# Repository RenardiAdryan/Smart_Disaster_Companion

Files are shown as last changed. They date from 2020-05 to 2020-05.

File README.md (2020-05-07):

# Smart_Disaster_Companion

This project is aimed to provide early warning system for fire.
it has IOT system that connect to the server, so users can know where the fire occured.
This thing will be connected with web application VIA firebase.com 

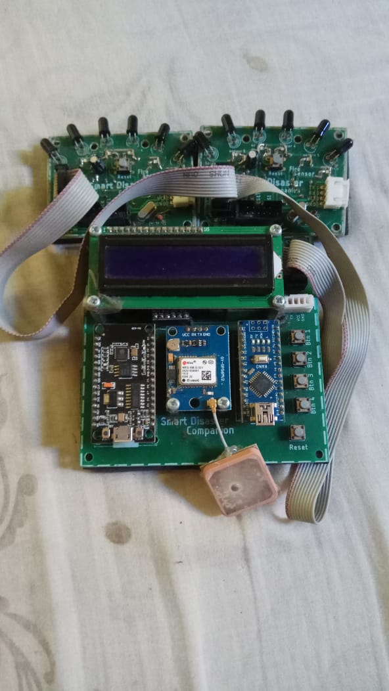
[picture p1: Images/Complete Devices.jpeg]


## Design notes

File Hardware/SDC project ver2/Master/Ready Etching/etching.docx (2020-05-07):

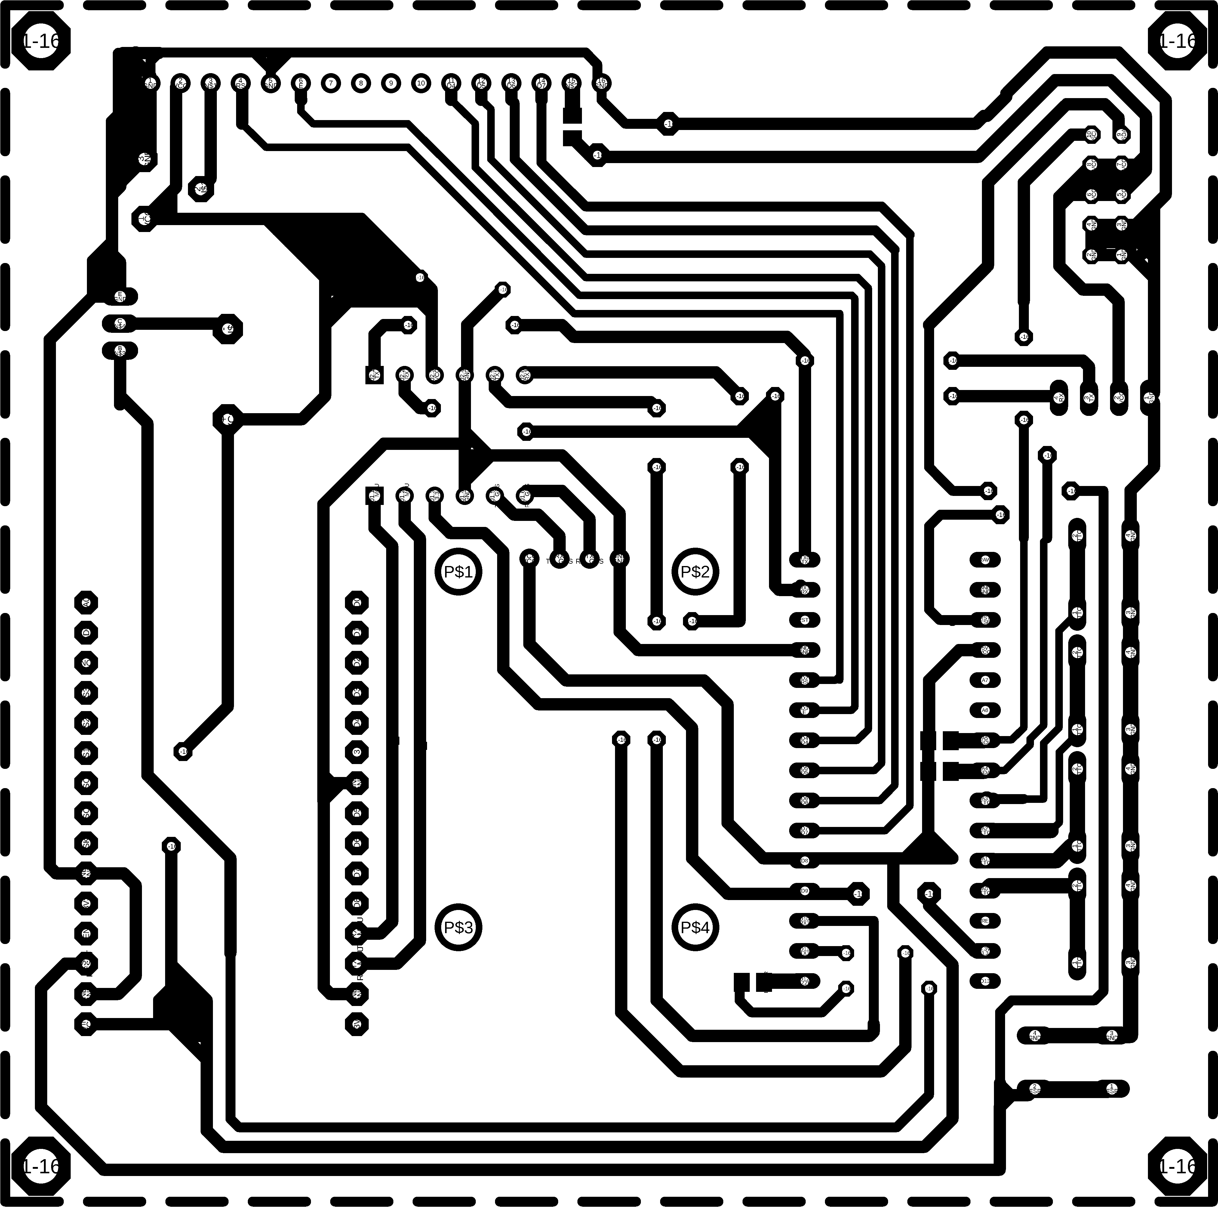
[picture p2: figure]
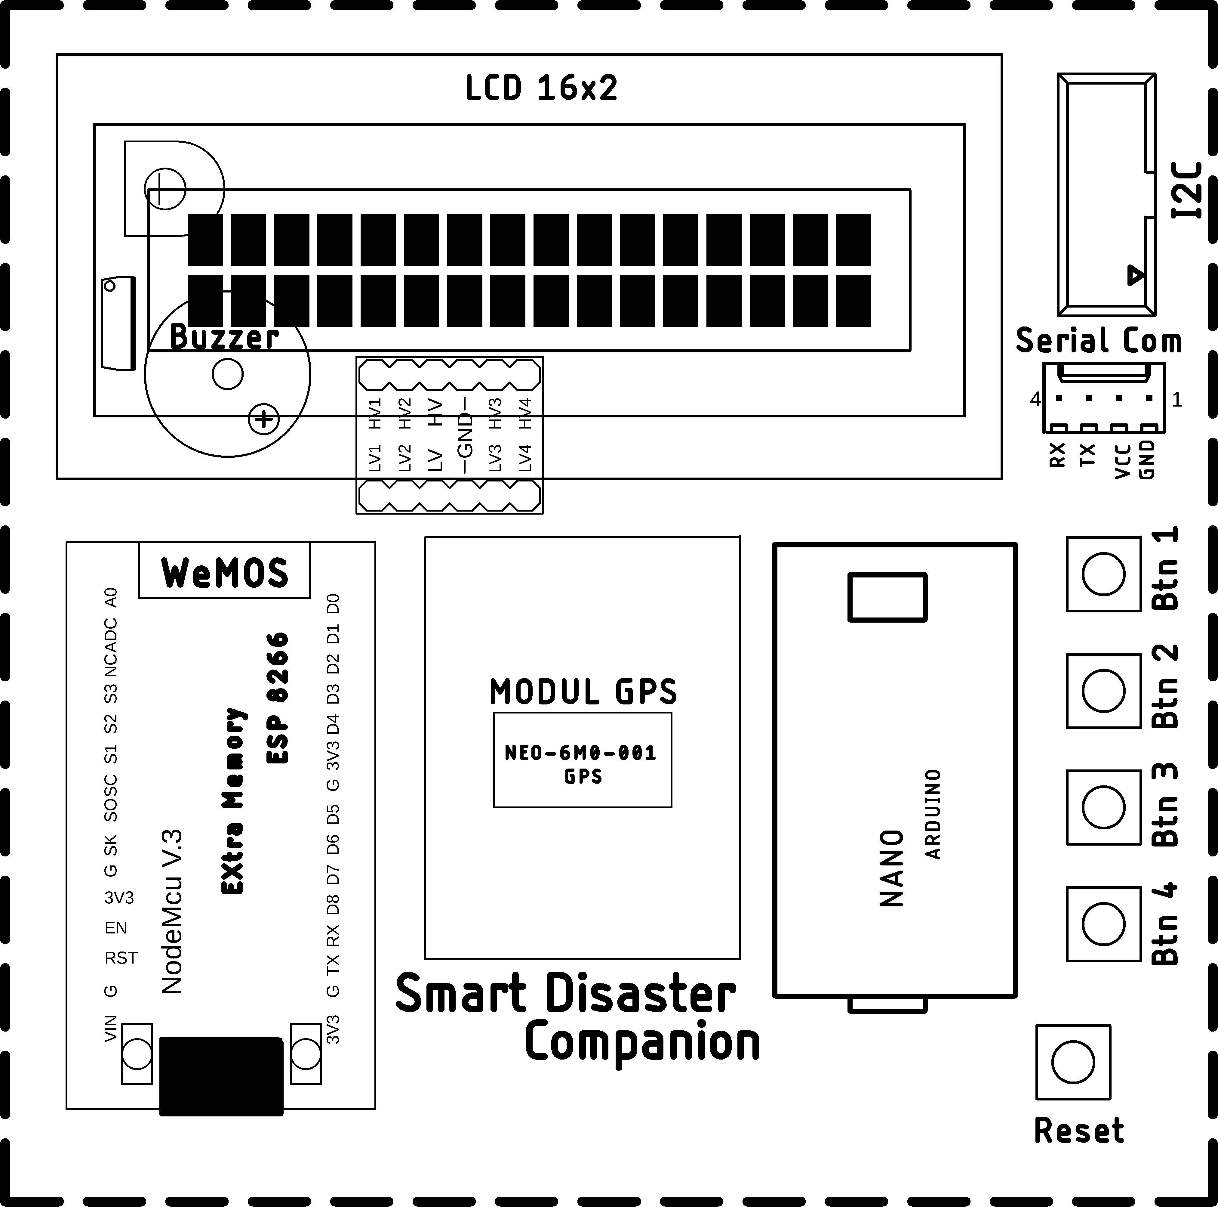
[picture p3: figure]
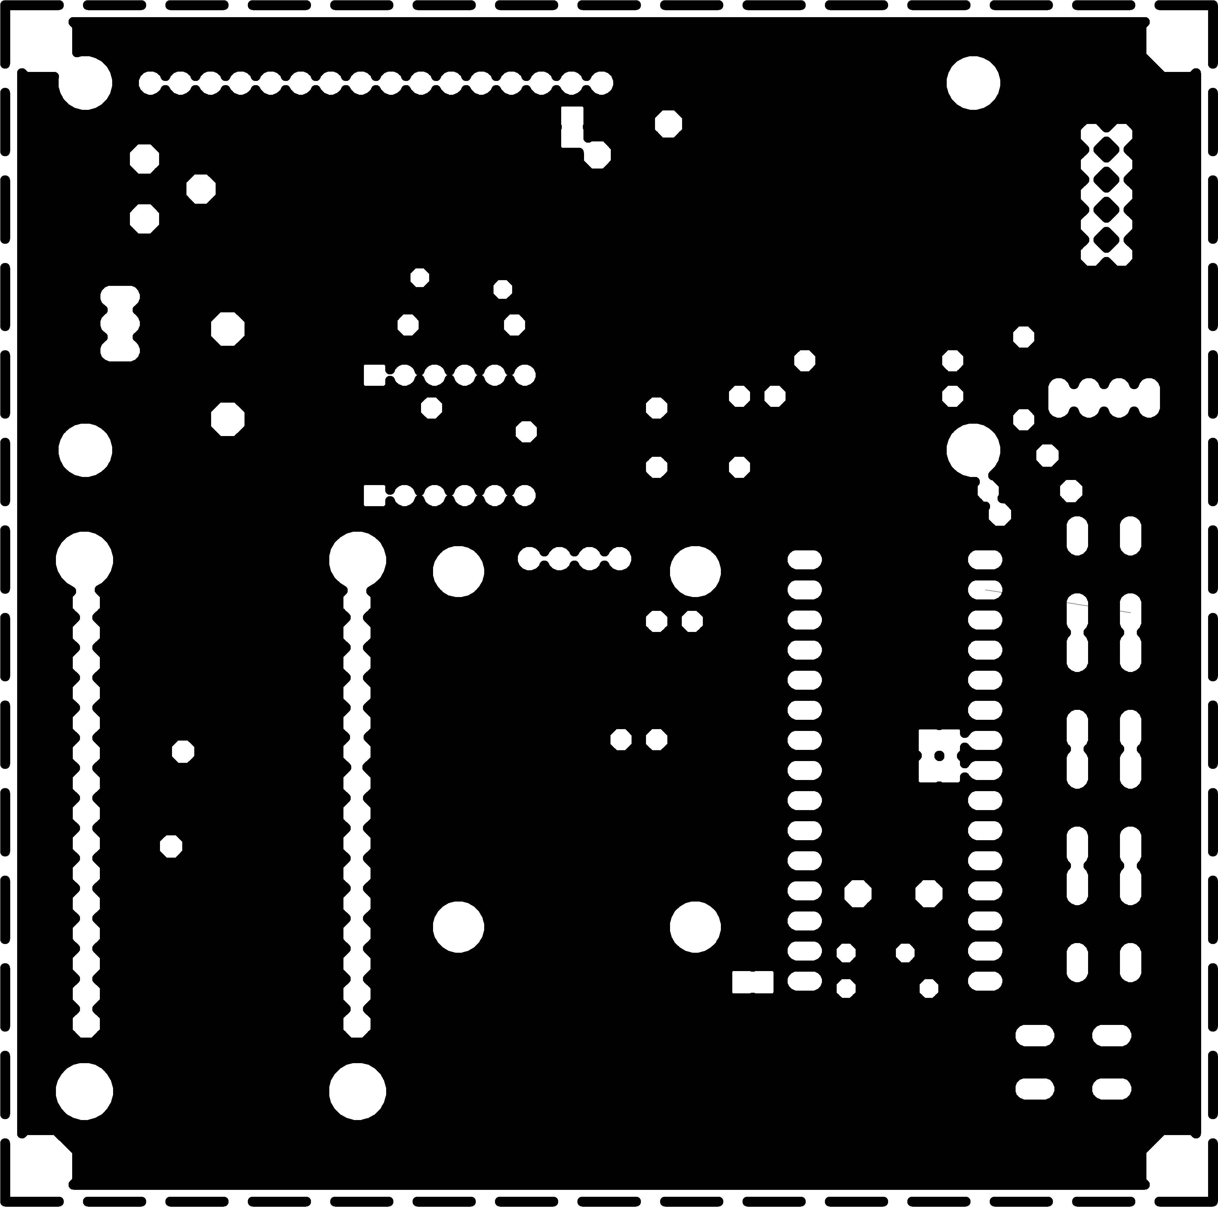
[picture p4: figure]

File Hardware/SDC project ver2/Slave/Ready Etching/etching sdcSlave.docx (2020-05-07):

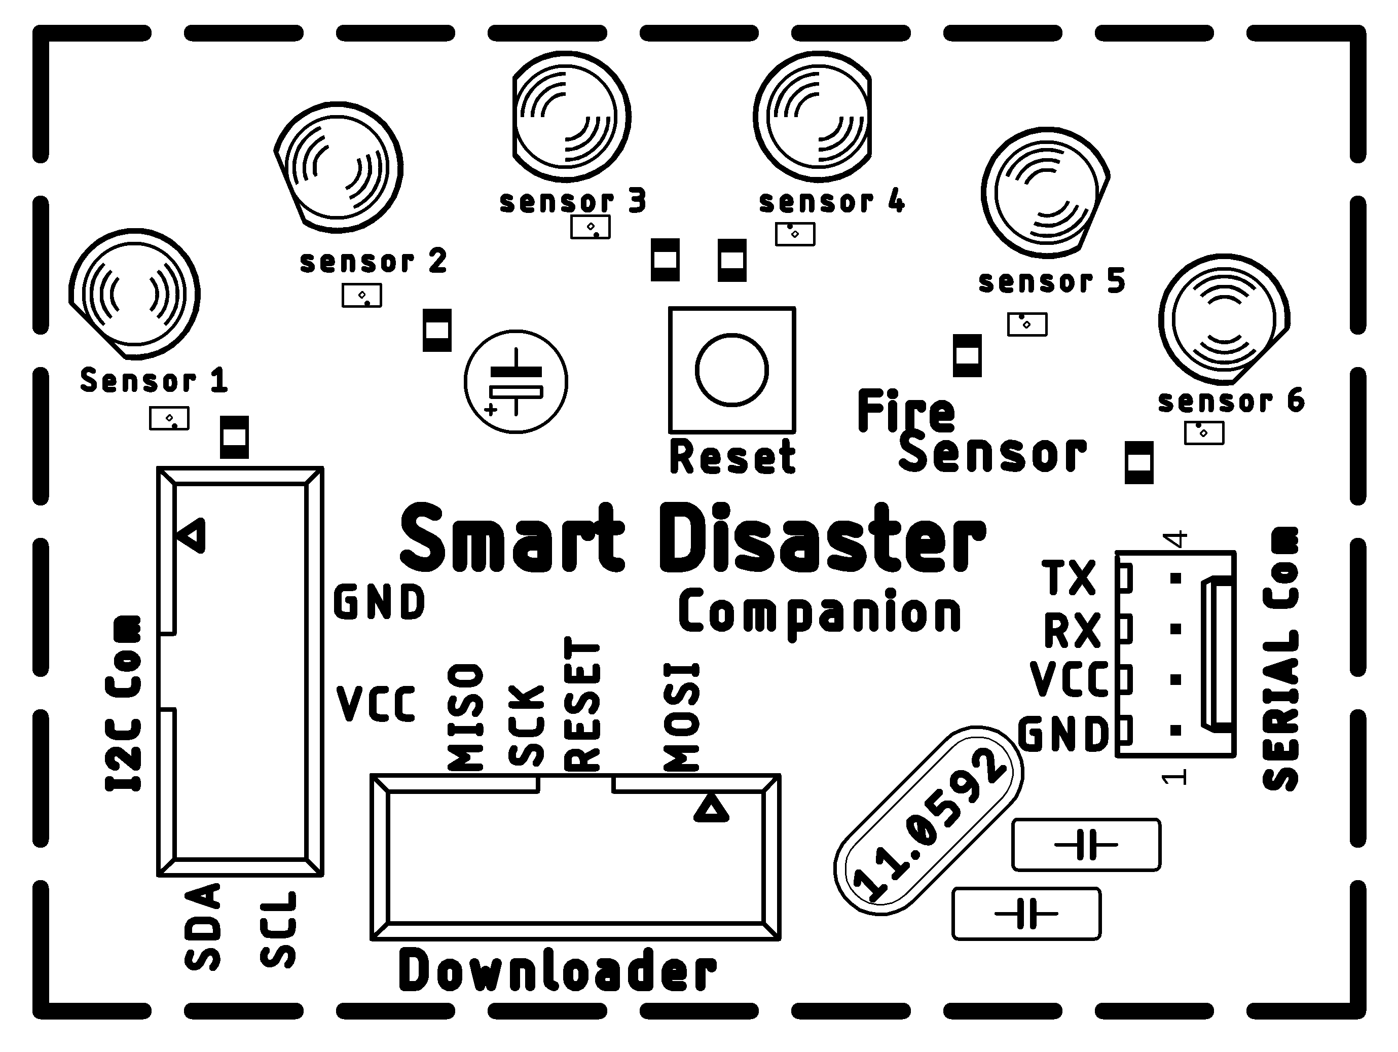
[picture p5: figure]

Silk Screen

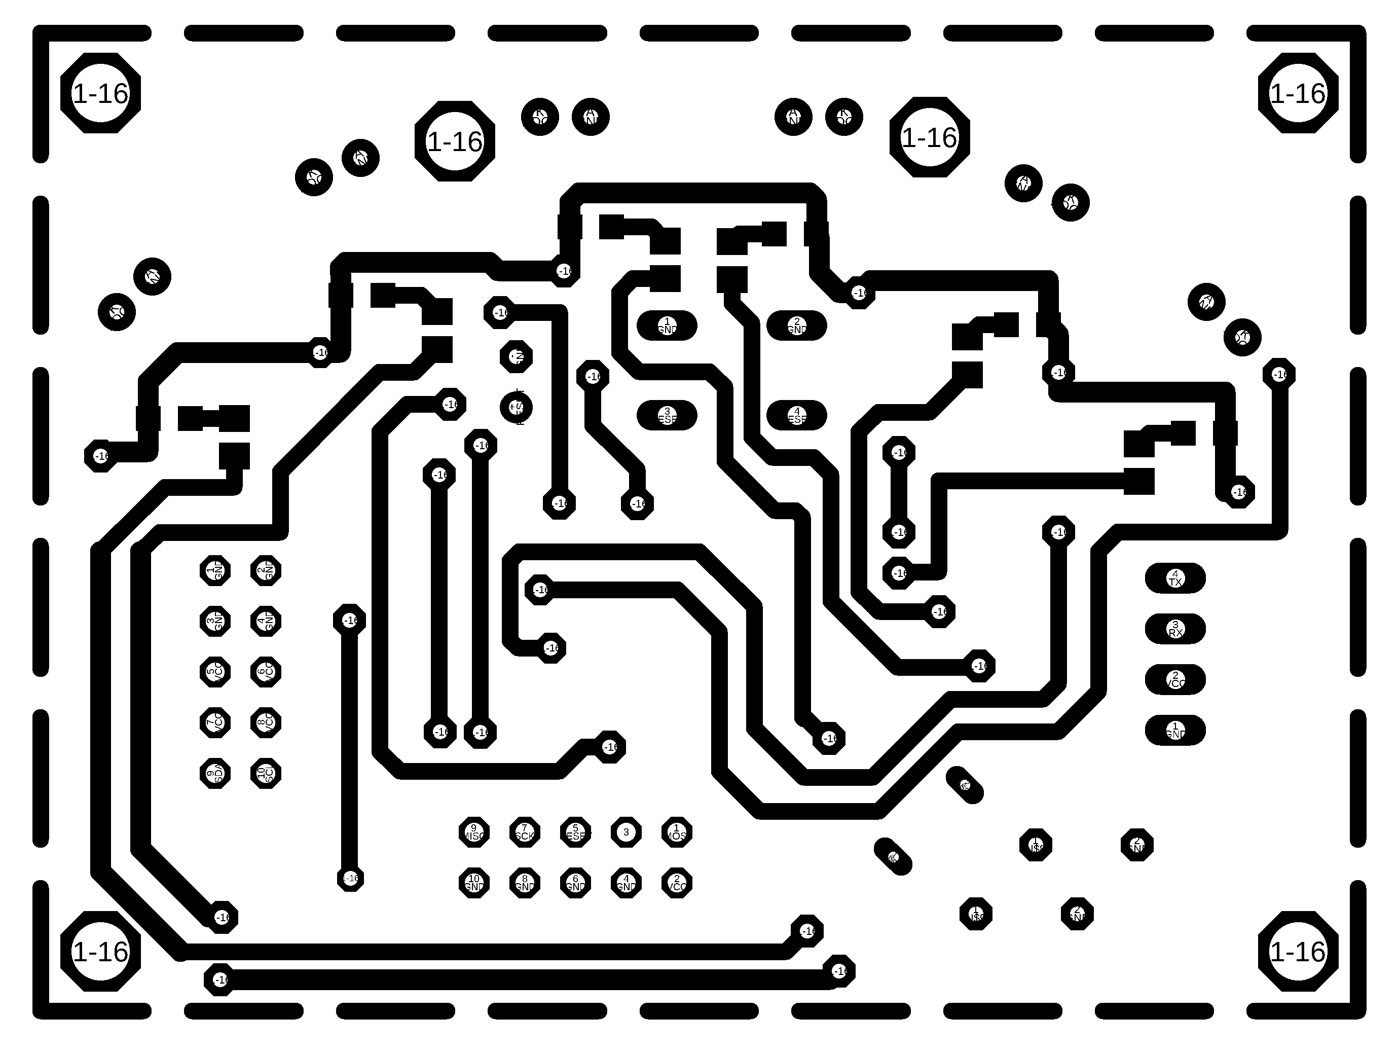
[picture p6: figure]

TOP

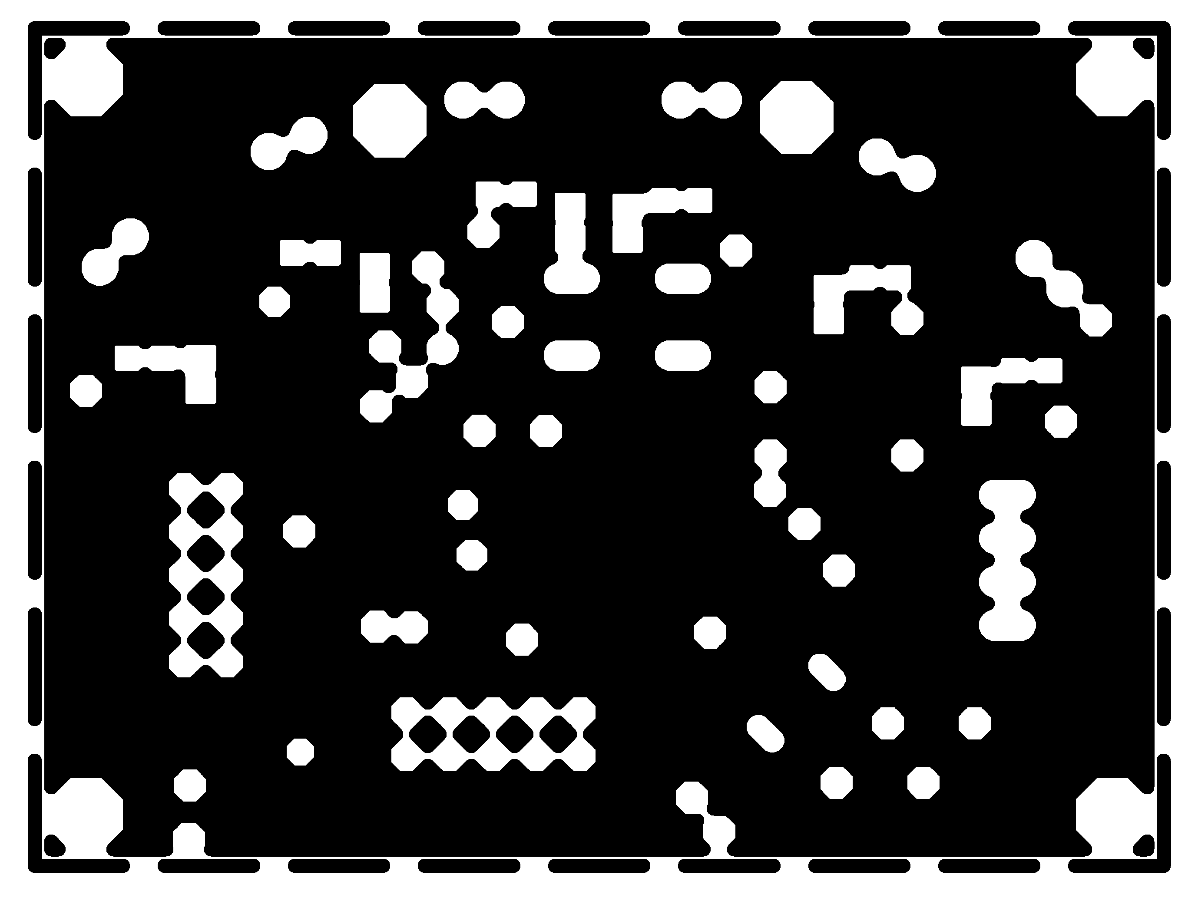
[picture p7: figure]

Masking TOP

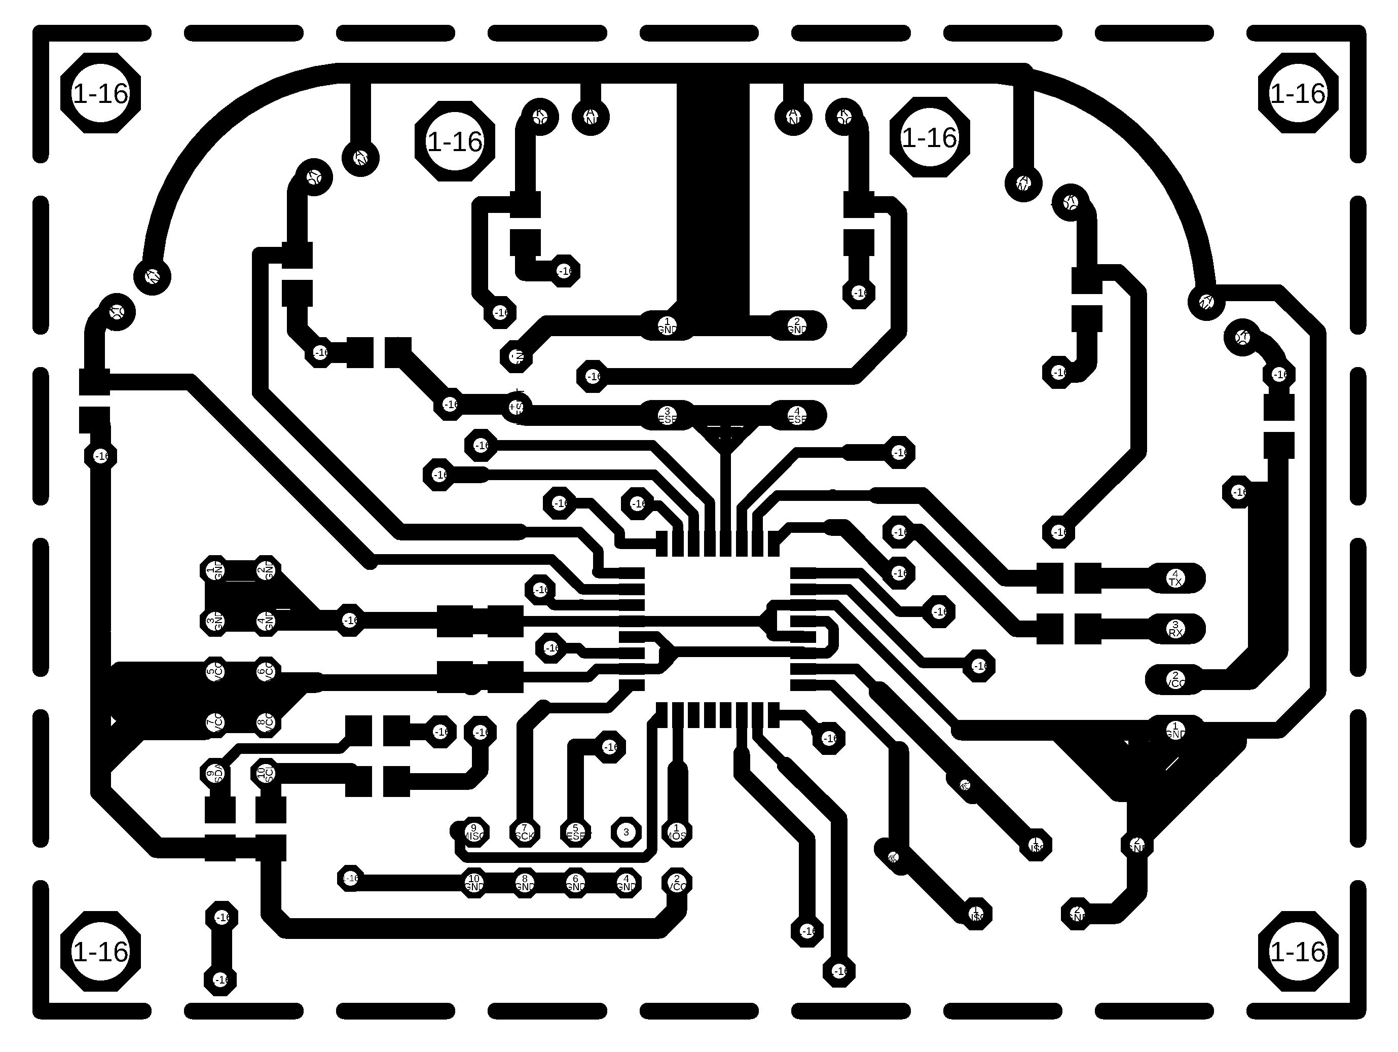
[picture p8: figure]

Buttom

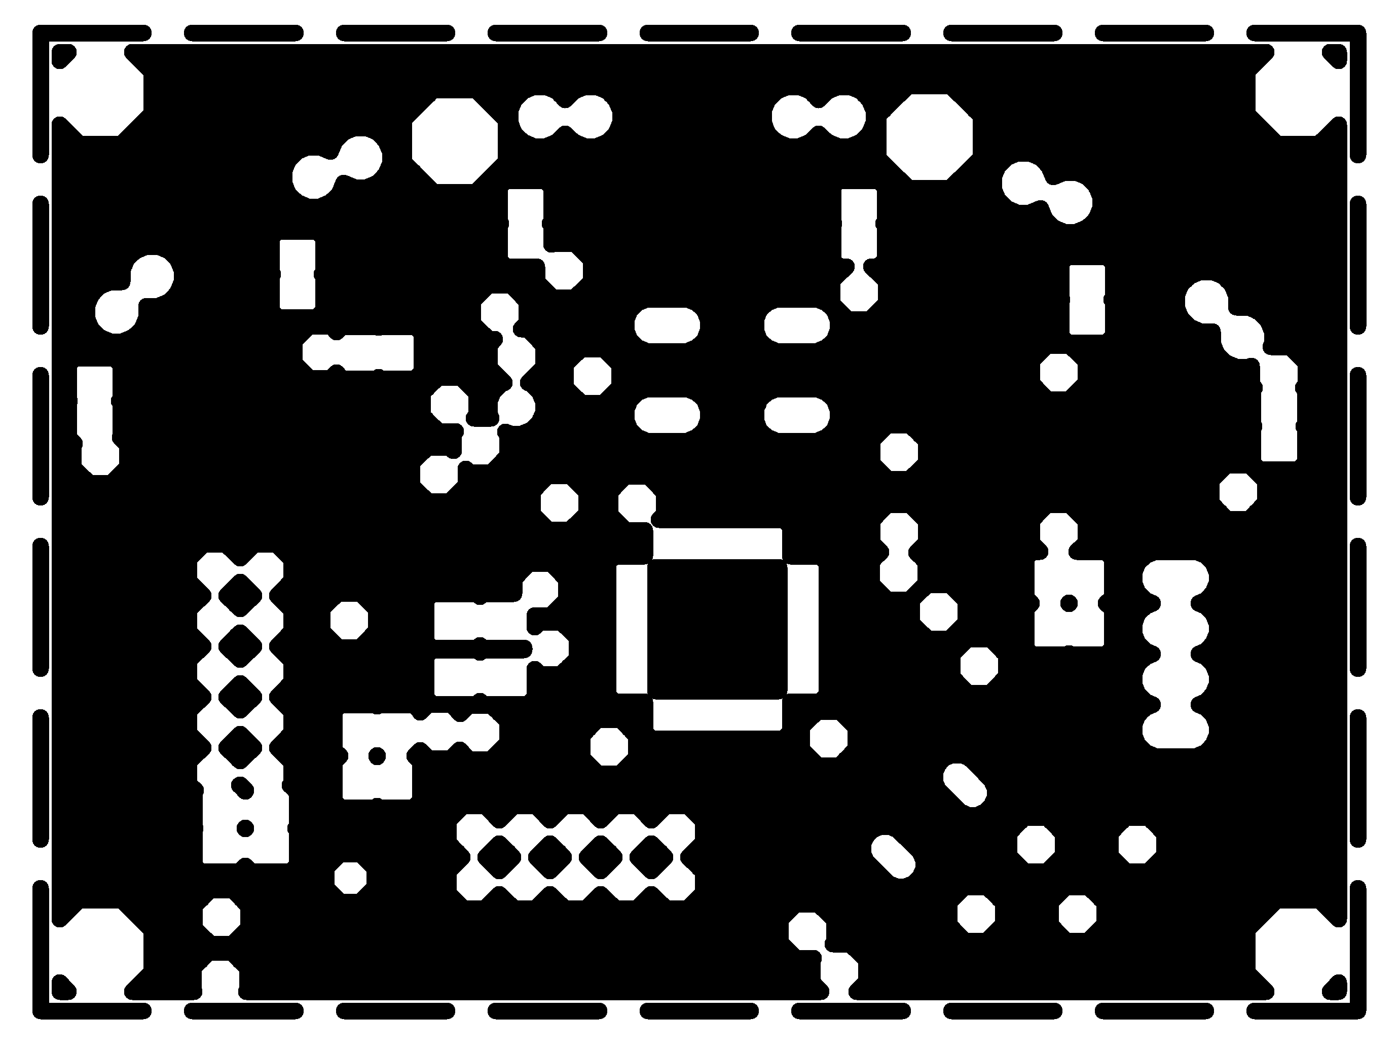
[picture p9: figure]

Masking Buttom

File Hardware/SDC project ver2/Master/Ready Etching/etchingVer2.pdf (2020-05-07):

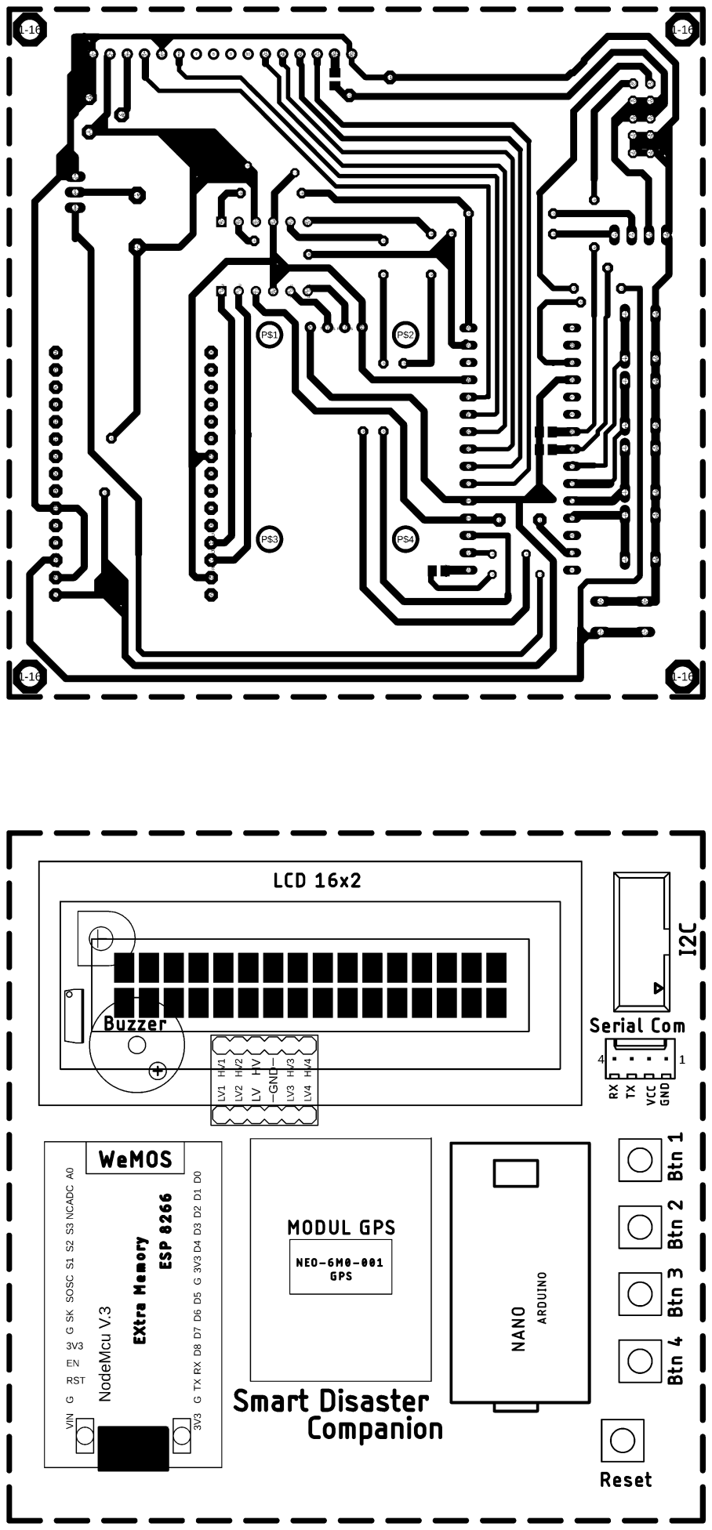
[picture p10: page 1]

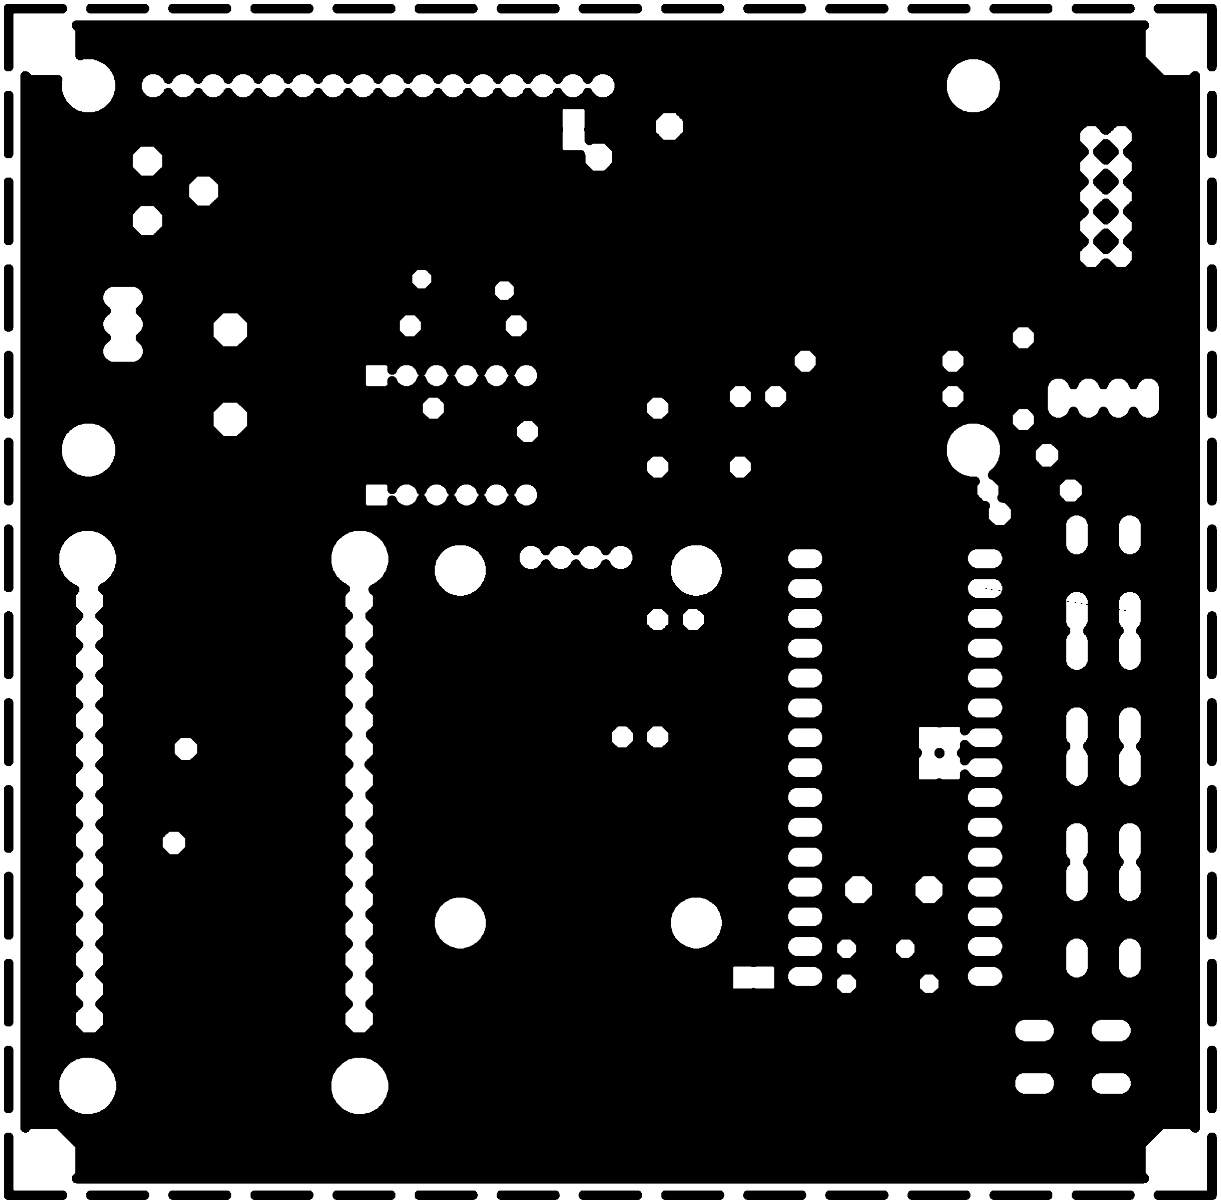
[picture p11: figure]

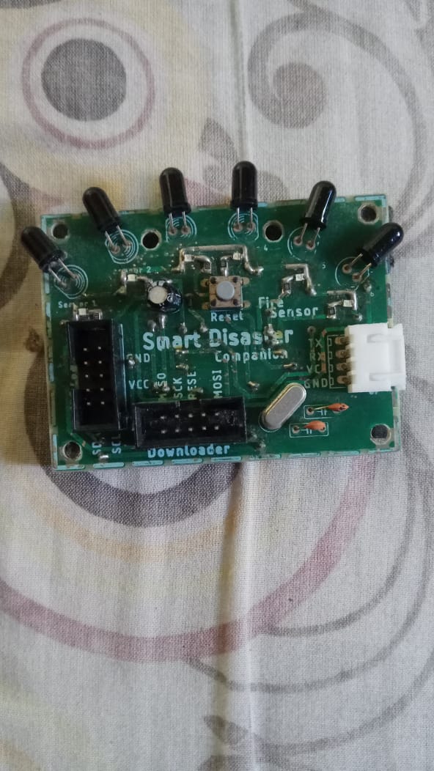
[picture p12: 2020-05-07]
Images/Slave Fire Sensors.jpeg

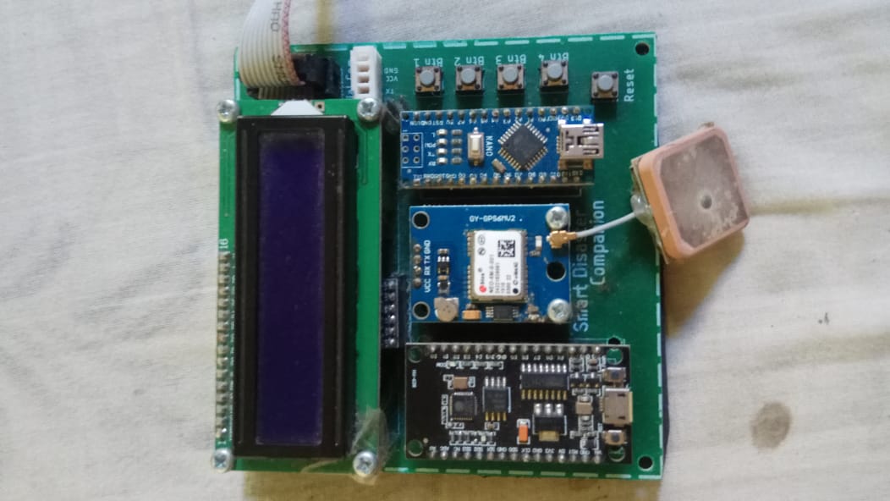
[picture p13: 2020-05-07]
Images/Master .jpeg

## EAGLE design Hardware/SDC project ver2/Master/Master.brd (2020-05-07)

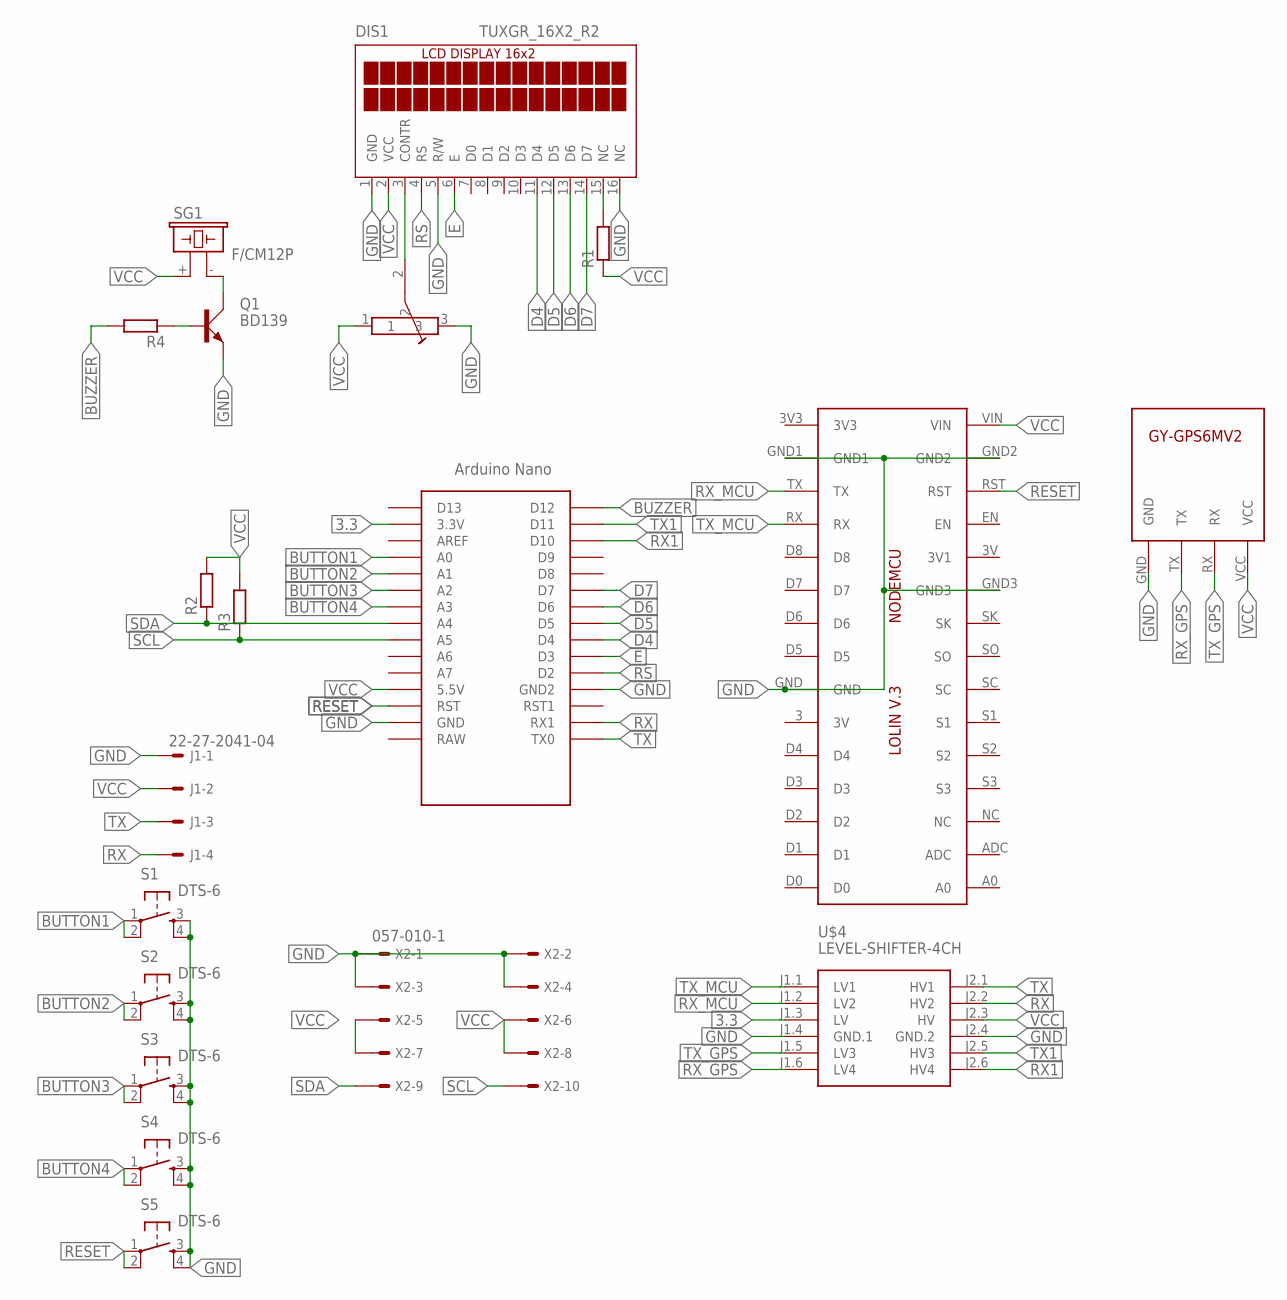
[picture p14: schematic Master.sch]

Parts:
DIS1: TUXGR_16X2_R2
IC1: LOLINV3
J1: 22-27-2041-04; 6410-04
Q1: BD139; TO126AV
R1, R2, R3, R4: R-EU_M0805; M0805
S1, S2, S3, S4, S5: DTS-6
SG1: F/CM12P
U$1: NANO
U$2: TRIMPOT
U$4: LEVEL-SHIFTER-4CH
U$5: GY-GPS6MV2
X2: 057-010-1

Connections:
3.3: U$1.3.3V, U$4.J1.3 (LV)
BUTTON1: S1.1, S1.2, U$1.A0
BUTTON2: S2.1, S2.2, U$1.A1
BUTTON3: S3.1, S3.2, U$1.A2
BUTTON4: S4.1, S4.2, U$1.A3
BUZZER: R4.2, U$1.D12
D4: DIS1.11 (D4), U$1.D4
D5: DIS1.12 (D5), U$1.D5
D6: DIS1.13 (D6), U$1.D6
D7: DIS1.14 (D7), U$1.D7
E: DIS1.6 (E), U$1.D3
GND: DIS1.1 (GND), DIS1.5 (R/W), DIS1.16 (NC), IC1.GND, IC1.GND1, IC1.GND2, IC1.GND3, J1.1, Q1.E, S1.3, S1.4, S2.3, S2.4, S3.3, S3.4, S4.3, S4.4, S5.3, S5.4, U$1.GND, U$1.GND1 (GND2), U$2.3, U$4.J1.4 (GND.1), U$4.J2.4 (GND.2), U$5.GND, X2.1, X2.2, X2.3, X2.4
unnamed: DIS1.3 (CONTR), U$2.2
unnamed: DIS1.15 (NC), R1.2
unnamed: Q1.B, R4.1
unnamed: Q1.C, SG1.- (2)
RESET: IC1.RST, S5.1, S5.2, U$1.RST
RS: DIS1.4 (RS), U$1.D2
RX: J1.4, U$1.RX1, U$4.J2.2 (HV2)
RX1: U$1.D10, U$4.J2.6 (HV4)
RX_GPS: U$4.J1.6 (LV4), U$5.TX
RX_MCU: IC1.TX, U$4.J1.2 (LV2)
SCL: R3.1, U$1.A5, X2.10
SDA: R2.1, U$1.A4, X2.9
TX: J1.3, U$1.TX0, U$4.J2.1 (HV1)
TX1: U$1.D11, U$4.J2.5 (HV3)
TX_GPS: U$4.J1.5 (LV3), U$5.RX
TX_MCU: IC1.RX, U$4.J1.1 (LV1)
VCC: DIS1.2 (VCC), IC1.VIN, J1.2, R1.1, R2.2, R3.2, SG1.+ (1), U$1.5V (5.5V), U$2.1, U$4.J2.3 (HV), U$5.VCC, X2.5, X2.6, X2.7, X2.8

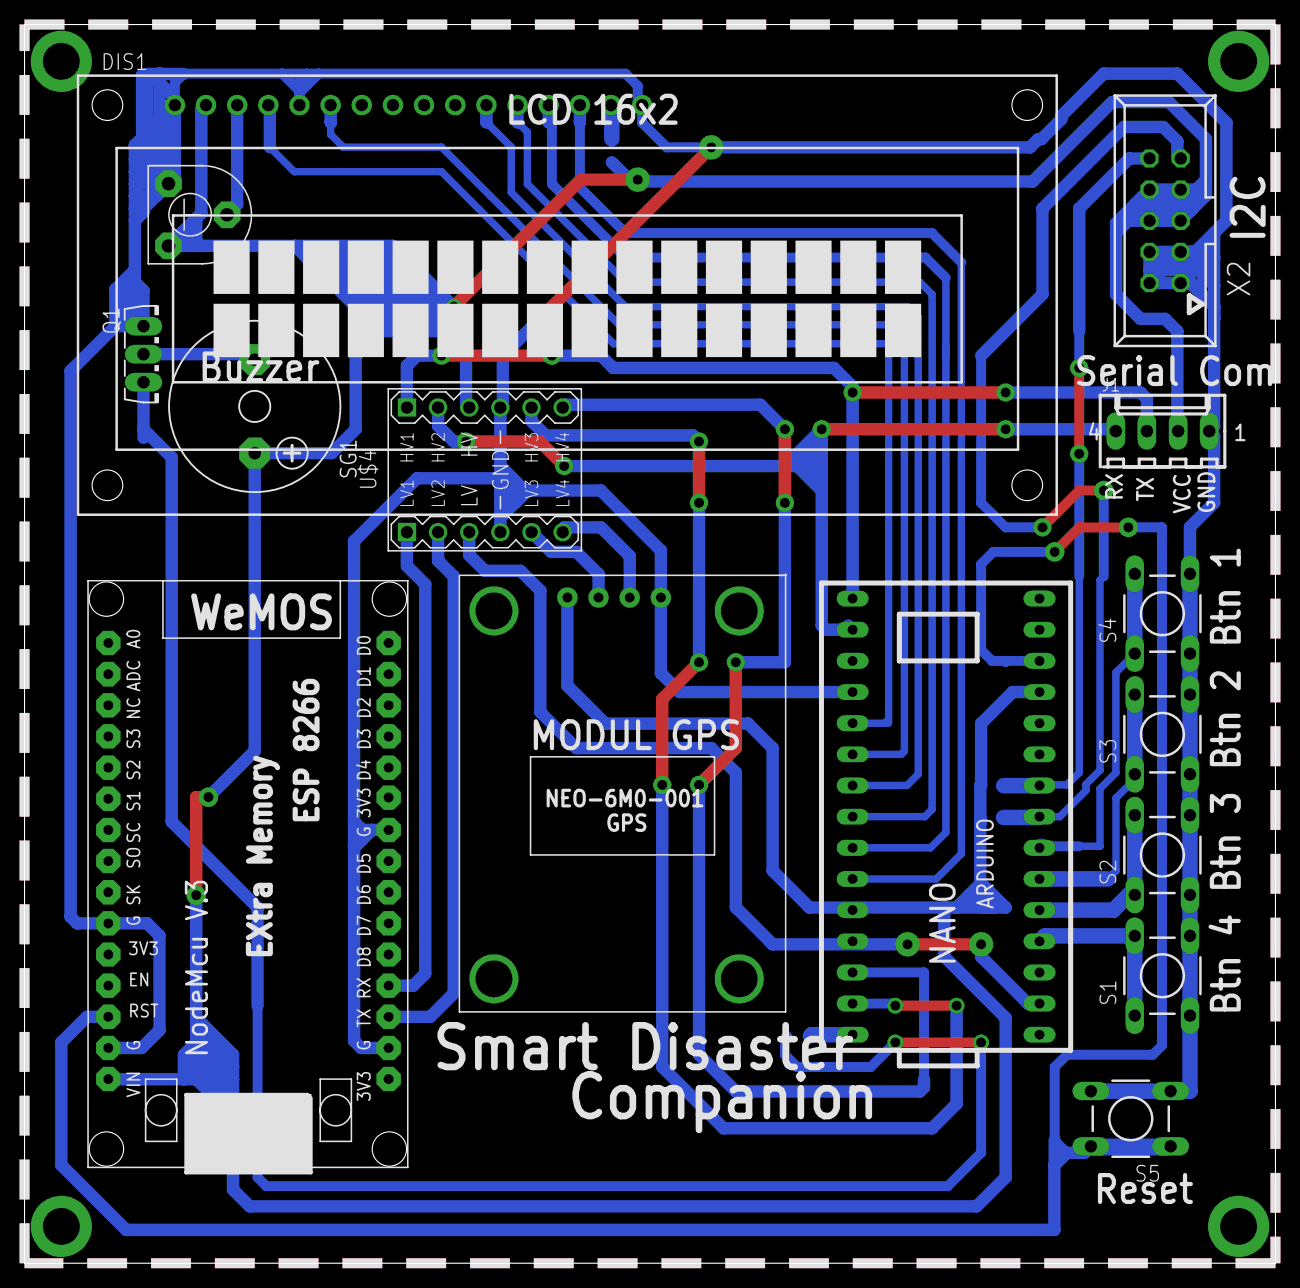
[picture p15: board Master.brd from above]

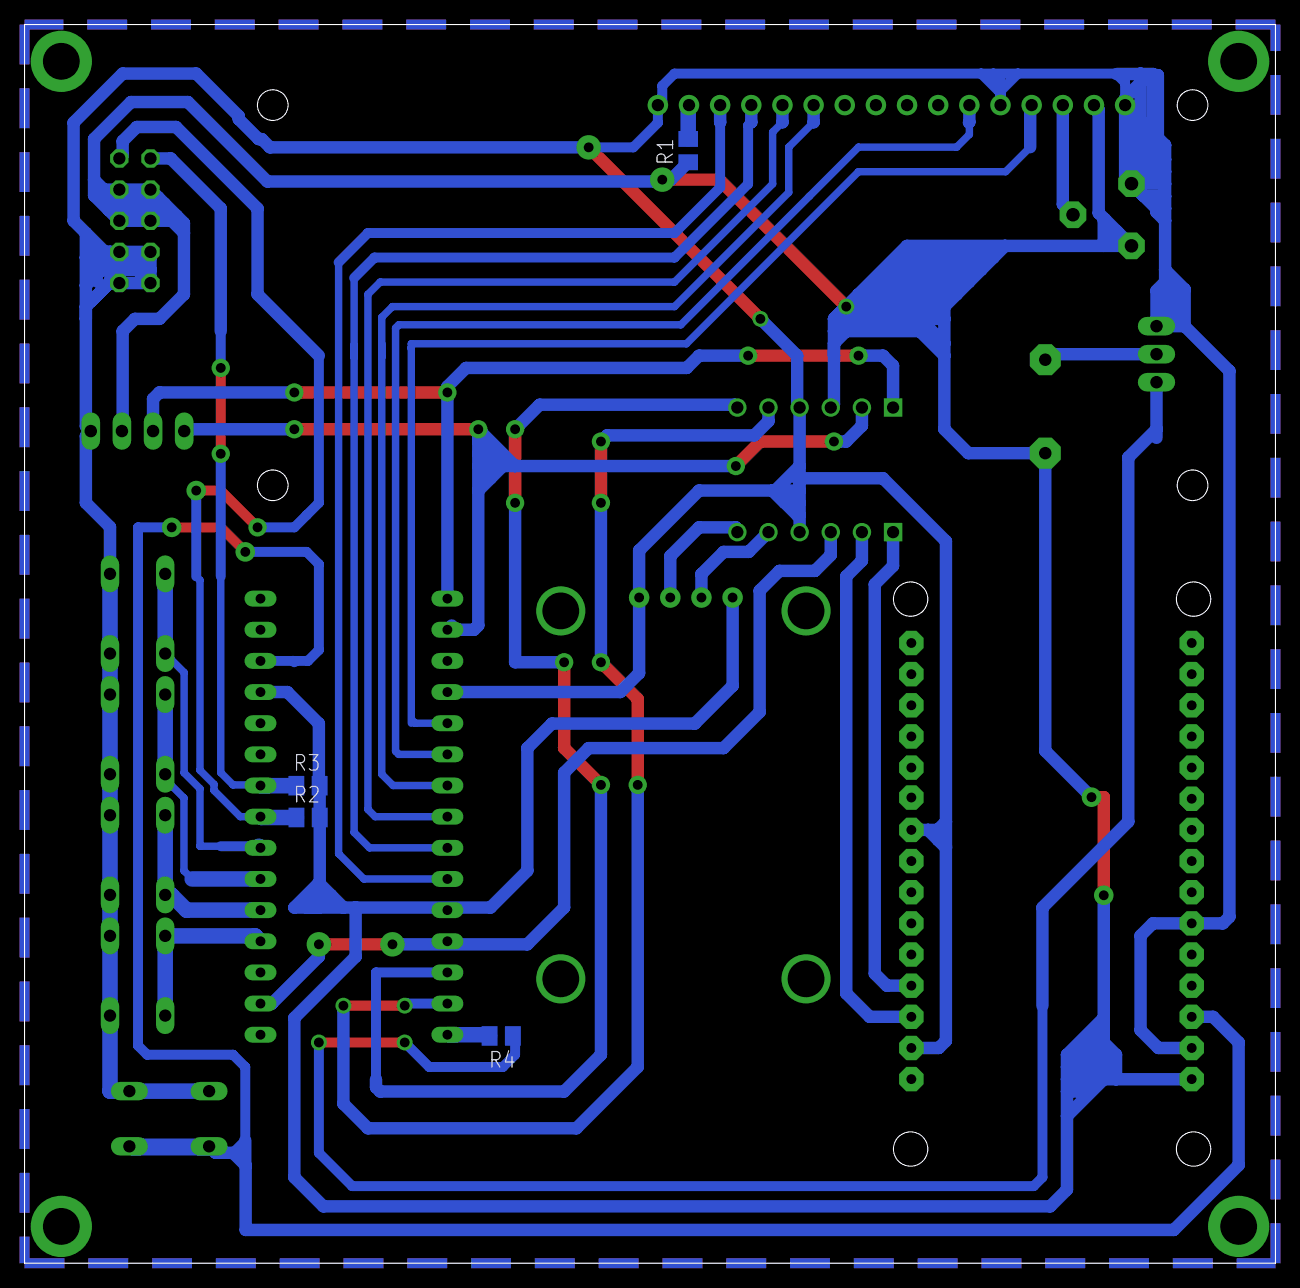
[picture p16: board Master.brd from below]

Board: 2 copper layers, 102.0 x 101.0 mm, 19 parts (4 on the bottom side), 29 nets.

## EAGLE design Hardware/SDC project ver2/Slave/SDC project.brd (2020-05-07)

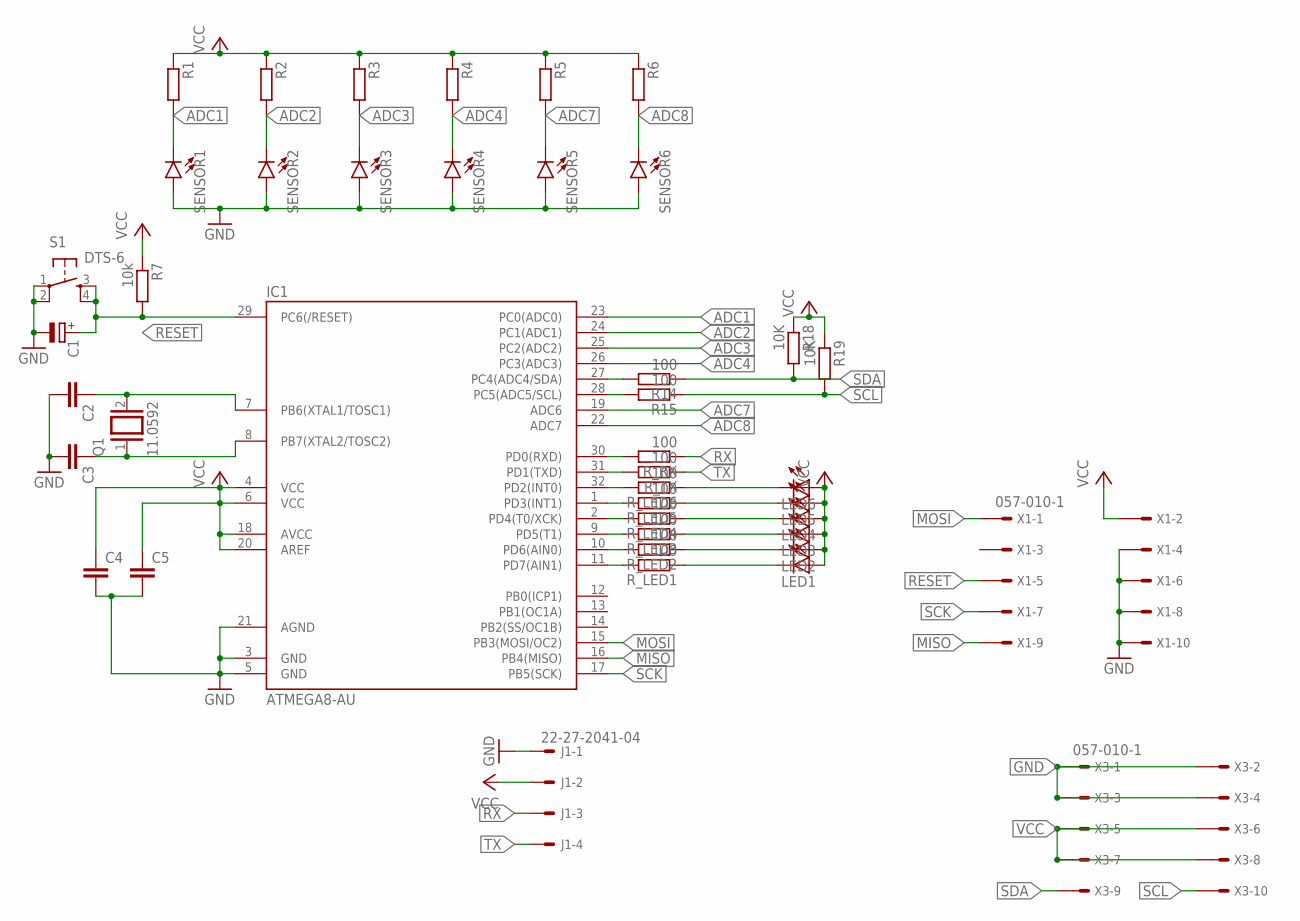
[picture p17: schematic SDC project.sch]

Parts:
C1: CPOL-EUE2.5-5; E2,5-5
C2, C3: C5/2.5; C5B2.5
C4, C5: C-EUC1206; C1206
IC1: ATMEGA8-AU; TQFP32-08
J1: 22-27-2041-04; 6410-04
LED1, LED2, LED3, LED4, LED5, LED6: LEDSML0805; SML0805
Q1: 11.0592; QS
R1, R2, R3, R4, R5, R6: R-EU_R0805; R0805
R7: 10k; R0805
R14, R15: 100; R0805
R18, R19: 10K; R0805
R_LED1, R_LED2, R_LED3, R_LED4, R_LED5, R_LED6: 100; R0805
R_RX: 100; R0805
R_TX: 100; R0805
S1: DTS-6
SENSOR1, SENSOR2, SENSOR3, SENSOR4, SENSOR5, SENSOR6: LED5MM; LED_5MM
X1, X3: 057-010-1

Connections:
ADC1: IC1.23 (PC0(ADC0)), R1.2, SENSOR1.K (C)
ADC2: IC1.24 (PC1(ADC1)), R2.2, SENSOR2.K (C)
ADC3: IC1.25 (PC2(ADC2)), R3.2, SENSOR3.K (C)
ADC4: IC1.26 (PC3(ADC3)), R4.2, SENSOR4.K (C)
ADC7: IC1.19 (ADC6), R5.2, SENSOR5.K (C)
ADC8: IC1.22 (ADC7), R6.2, SENSOR6.K (C)
GND: C1.-, C2.2, C3.2, C4.2, C5.2, IC1.3 (GND), IC1.5 (GND), IC1.21 (AGND), J1.1, S1.1, S1.2, SENSOR1.A, SENSOR2.A, SENSOR3.A, SENSOR4.A, SENSOR5.A, SENSOR6.A, X1.4, X1.6, X1.8, X1.10, X3.1, X3.2, X3.3, X3.4
MISO: IC1.16 (PB4(MISO)), X1.9
MOSI: IC1.15 (PB3(MOSI/OC2)), X1.1
unnamed: IC1.30 (PD0(RXD)), R_RX.2
unnamed: IC1.31 (PD1(TXD)), R_TX.2
unnamed: IC1.27 (PC4(ADC4/SDA)), R14.2
unnamed: C2.1, IC1.7 (PB6(XTAL1/TOSC1)), Q1.2
unnamed: C3.1, IC1.8 (PB7(XTAL2/TOSC2)), Q1.1
unnamed: IC1.28 (PC5(ADC5/SCL)), R15.2
unnamed: IC1.32 (PD2(INT0)), R_LED6.2
unnamed: IC1.1 (PD3(INT1)), R_LED5.2
unnamed: IC1.2 (PD4(T0/XCK)), R_LED4.2
unnamed: IC1.9 (PD5(T1)), R_LED3.2
unnamed: IC1.10 (PD6(AIN0)), R_LED2.2
unnamed: IC1.11 (PD7(AIN1)), R_LED1.2
unnamed: LED6.C, R_LED6.1
unnamed: LED5.C, R_LED5.1
unnamed: LED4.C, R_LED4.1
unnamed: LED3.C, R_LED3.1
unnamed: LED2.C, R_LED2.1
unnamed: LED1.C, R_LED1.1
RESET: C1.+, IC1.29 (PC6(/RESET)), R7.2, S1.3, S1.4, X1.5
RX: J1.3, R_RX.1
SCK: IC1.17 (PB5(SCK)), X1.7
SCL: R15.1, R19.2, X3.10
SDA: R14.1, R18.2, X3.9
TX: J1.4, R_TX.1
VCC: C4.1, C5.1, IC1.4 (VCC), IC1.6 (VCC), IC1.18 (AVCC), IC1.20 (AREF), J1.2, LED1.A, LED2.A, LED3.A, LED4.A, LED5.A, LED6.A, R1.1, R2.1, R3.1, R4.1, R5.1, R6.1, R7.1, R18.1, R19.1, X1.2, X3.5, X3.6, X3.7, X3.8

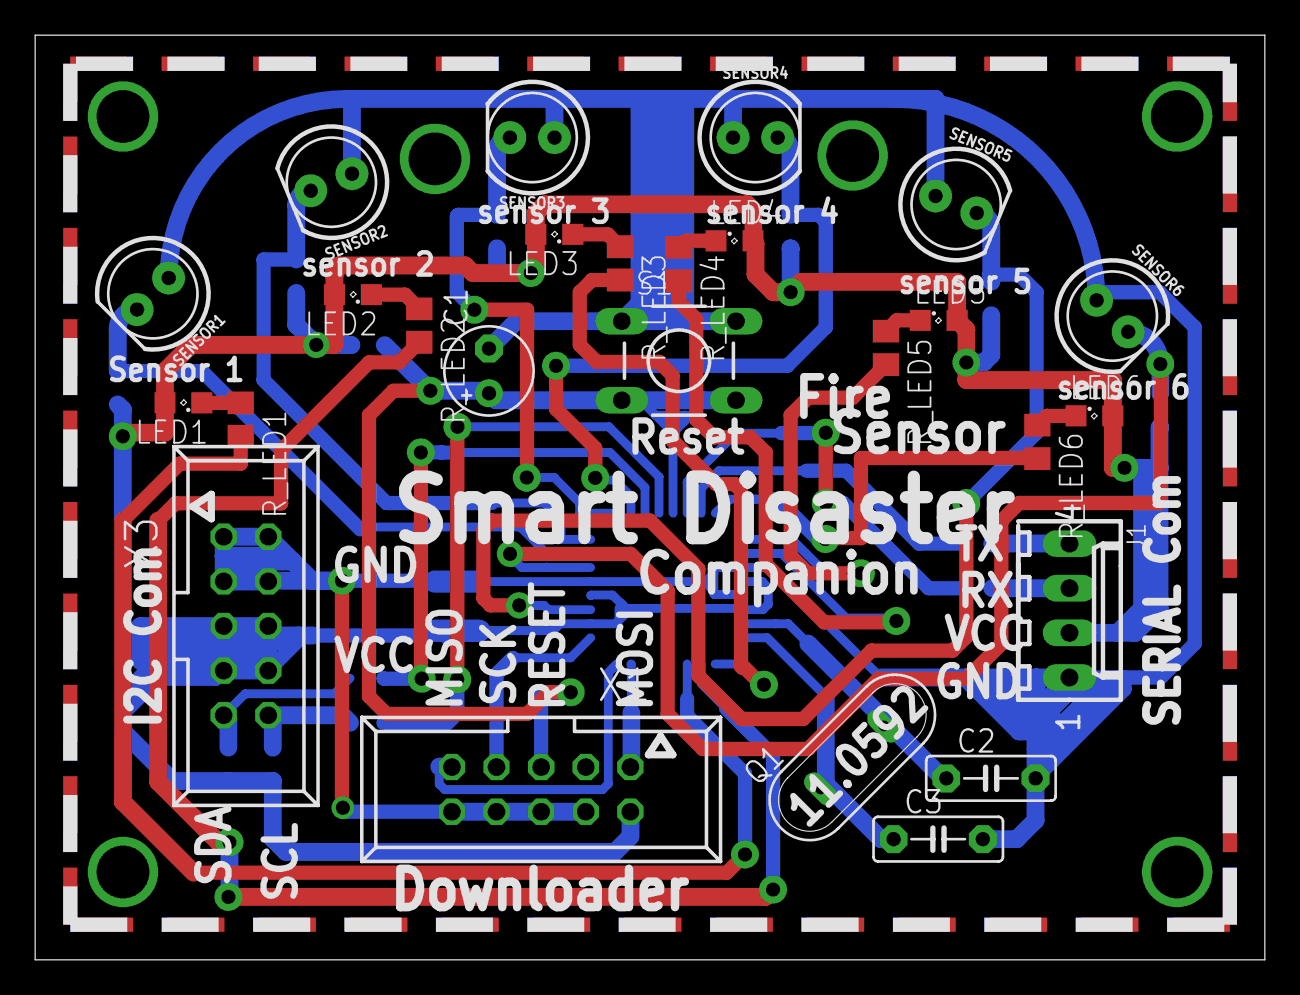
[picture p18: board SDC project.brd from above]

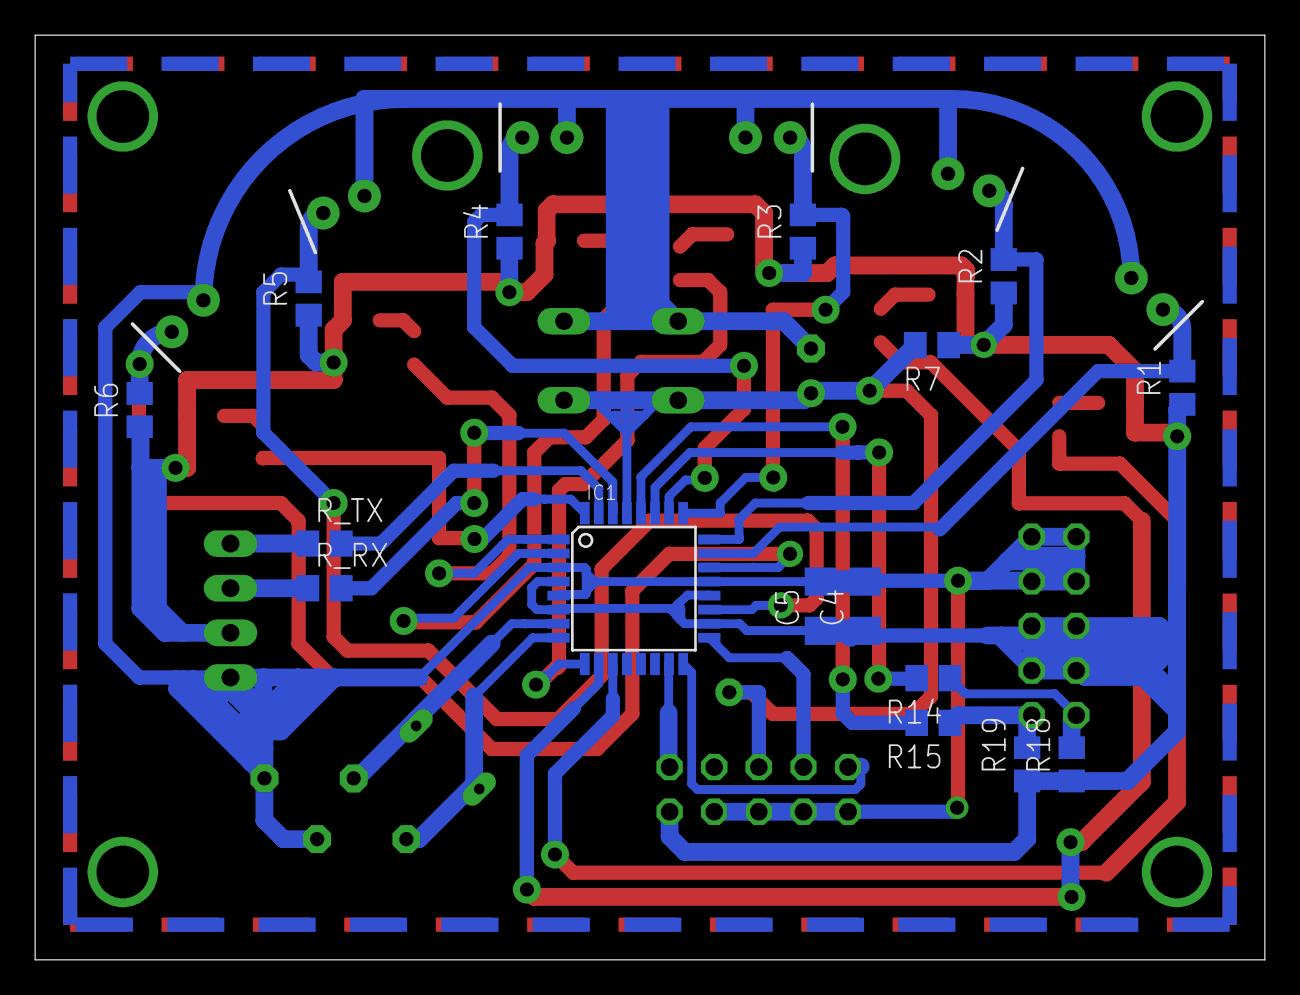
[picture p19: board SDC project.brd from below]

Board: 2 copper layers, 70.0 x 52.6 mm, 42 parts (16 on the bottom side), 34 nets.

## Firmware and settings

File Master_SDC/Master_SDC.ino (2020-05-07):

#include "define.h"
int dtSensor[3][7];
int sensor[4];
int fireStatus;
char showing=1;
void setup() {
  // put your setup code here, to run once:
  lcd.begin(16,2);
  Serial.begin(115200); // connect serial 
  gpsSerial.begin(9600); // connect gps sensor
  Wire.begin(); //Connect to fire ensor 

  pinMode(BUTTON1,INPUT_PULLUP);
  pinMode(BUTTON2,INPUT_PULLUP);
  pinMode(BUTTON3,INPUT_PULLUP);
  pinMode(BUTTON4,INPUT_PULLUP);
  
  pinMode(BUZZER_PIN,OUTPUT);
  pinMode(LEDBUILTIN,OUTPUT);

  lcd.setCursor(0,0);
  lcd.print("..STARTING UP..");
  lcd.setCursor(0,1);
  lcd.print("___..SDC..___");
  Buzzer();
  delay(1000);
  lcd.clear();    

}
float nowTime,prevTime;int intervalTime= 100;
void loop() {
  // put your main code here, to run repeatedly:

GetGPS();

ReadFireSensor();
if(sensor[1]!=999 ||sensor[2]!=999  ){fireStatus =1 ;
digitalWrite(BUZZER_PIN,HIGH);
}
else {fireStatus =0 ; digitalWrite(BUZZER_PIN,LOW);}

buttonScan();
LCDshow();

nowTime = millis();
if(nowTime-prevTime>intervalTime){
sendToESP();
prevTime = nowTime;
  digitalWrite(LEDBUILTIN, !(digitalRead(LEDBUILTIN)));  //Invert Current State of LED 

}

}


void sendToESP(){Serial.print("#");
 Serial.print(latitude,6);Serial.print(",");
 Serial.print(longitude,6);Serial.print(",");
 Serial.print(fireStatus);Serial.println("!");
}





void LCDshow(){
  static int counter;
  if(counter++>50){counter=0;
     lcd.clear();
  if(showing==1){   
            if(fireStatus == 0 ){     
              lcd.setCursor(0,0);
              lcd.print("SDC IDle !!"); 
                
              lcd.setCursor(0,1);
              lcd.print("Fire undetected"); 
                      }
              
            else   if(fireStatus == 1 ){     
              lcd.setCursor(0,0);
              lcd.print("FIre Detect !!"); 
                
              lcd.setCursor(0,1);
              if(sensor[1]!=999){
              //lcd.print(getDegree(sensor[1]),2); lcd.print(">1");lcd.print("|");
              float degree= sensor[1];
              if(degree<3000){lcd.print("Sensor 1->");lcd.print("Right");}
              else if(degree>=3000 && degree<=4000 ){lcd.print("Sensor 1->");lcd.print("Center");}
              else if(degree>4000){lcd.print("Sensor 1->");lcd.print("Left");}
              }
                
              if(sensor[2]!=999){
              //lcd.print("|");lcd.print(getDegree(sensor[2]),2); lcd.print(">2");}
              float degree= sensor[2];
              if(degree<3000){lcd.print("Sensor 2->");lcd.print("Right");}
              else if(degree>=3000 && degree<=4000 ){lcd.print("Sensor 2->");lcd.print("Center");}
              else if(degree>4000){lcd.print("Sensor 2->");lcd.print("Left");} 
                     
                      }
              
                }

  }
    else if (showing==2){      
      lcd.setCursor(0,0);
      lcd.print("Lat = "); lcd.print(latitude,5);
      lcd.setCursor(0,1);
      lcd.print("Long = "); lcd.print(longitude,5);

    }
}
}

void buttonScan(){
  if(isButtonPressed(BUTTON1)){showing = 1; }
  if(isButtonPressed(BUTTON2)){showing = 2; }
  if(isButtonPressed(BUTTON3)){showing = 3; }
  
  
  }

int isButtonPressed(int pin)//Function to eliminate debouncing
{
  if(!digitalRead(pin))
  {
    delay(5);
    if     (!digitalRead(pin)) return 1;
    else if(digitalRead(pin)) return 0;
  }
  
  return 0;
}



float getDegree(float degree){
//      ------------
//      |         /
//      |       /
//      |     /
//      |   /
//      | /
//tinggi = 11.09 , alas = 29 maka arcTan = 21 derajat     
  degree = map(degree,0,5000,0,21);


 return degree; 
  }
int i2c_read(int id)
{
  Wire.requestFrom(id, 1); // request 1 bytes from slave device #ID
  int data = 0;
  while (Wire.available()) { // slave may send less than requested
    data = Wire.read(); // receive a byte as character
  }

  if(id == fireSensor1){
  dtSensor[1][6] = ((data & 0b00100000) >> 5);
  dtSensor[1][5] = ((data & 0b00010000) >> 4);
  dtSensor[1][4] = ((data & 0b00001000) >> 3);
  dtSensor[1][3] = ((data & 0b00000100) >> 2);
  dtSensor[1][2] = ((data & 0b00000010) >> 1);
  dtSensor[1][1] = data & 0b00000001;
  }

  if(id == fireSensor2){
  dtSensor[2][6] = ((data & 0b00100000) >> 5);
  dtSensor[2][5] = ((data & 0b00010000) >> 4);
  dtSensor[2][4] = ((data & 0b00001000) >> 3);
  dtSensor[2][3] = ((data & 0b00000100) >> 2);
  dtSensor[2][2] = ((data & 0b00000010) >> 1);
  dtSensor[2][1] = data & 0b00000001;
  }

  return data;
}

void ReadFireSensor(){
  
  i2c_read(fireSensor1); 
  i2c_read(fireSensor2);
  
  if (dtSensor[1][6] || dtSensor[1][5] || dtSensor[1][4] || dtSensor[1][3] || dtSensor[1][2] || dtSensor[1][1]) {
    //Calculate the weighted mean!!-->RING sensor
    sensor[1] = (5000  * dtSensor[1][6] + 4000 * dtSensor[1][5] + 3000 * dtSensor[1][4] + 2000 * dtSensor[1][3] + 1000 * dtSensor[1][2] + 0 * dtSensor[1][1]) /
             (dtSensor[1][6] + dtSensor[1][5] + dtSensor[1][4] + dtSensor[1][3] + dtSensor[1][2] + dtSensor[1][1]);
  }
  else sensor[1] = 999;
  
  if (dtSensor[2][6] || dtSensor[2][5] || dtSensor[2][4] || dtSensor[2][3] || dtSensor[2][2] || dtSensor[2][1]) {
    //Calculate the weighted mean!!-->RING sensor
    sensor[2] = (5000  * dtSensor[2][6] + 4000 * dtSensor[2][5] + 3000 * dtSensor[2][4] + 2000 * dtSensor[2][3] + 1000 * dtSensor[2][2] + 0 * dtSensor[2][1]) /
             (dtSensor[2][6] + dtSensor[2][5] + dtSensor[2][4] + dtSensor[2][3] + dtSensor[2][2] + dtSensor[2][1]);
  }
  else sensor[2] = 999;
  
}


//int baca = i2c_read(0x30);
//Serial.print("Data i2C sensor 1= ");
//Serial.print(baca);Serial.print(" || ");
// baca = i2c_read(0x31);
//Serial.print("Data i2C sensor 2= ");
//Serial.println(baca);

//Serial.print("Data sensor 1 = ");
//Serial.print( sensor[1] );Serial.print(" || ");
//Serial.print("Data sensor 2 = ");
//Serial.println( sensor[2] );

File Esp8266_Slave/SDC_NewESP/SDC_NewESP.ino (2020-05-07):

#include <ESP8266WiFi.h>
#include <FirebaseArduino.h>
#include <Firebase.h>

#include <Ticker.h>  //Ticker Library

Ticker interrupt;
#define BUFFER  50
#define LEDBUILTIN D0


//#define FIREBASE_HOST "smartdis-f49ae.firebaseio.com"
//#define FIREBASE_AUTH "sxTbbdGxGuEiS30FjNpqpoVRIadB2WgExRk5woAR"

//#define FIREBASE_HOST "smartdisastercompanion-714c4.firebaseio.com"
//#define FIREBASE_AUTH "tSnFs5rUy862Gjr6DLluZcwCVHB5DSN6mLoVnCma"
//#define FIREBASE_AUTH   "dYvCq162RPegfqSf3For3GfgSz6SJX134lFaxQWQ"
//#define FIREBASE_AUTH   "bavHpwWBgrIHzPt71D0Cteu7J7EBI5weFQJj3I8T"


#define FIREBASE_HOST "smartdisastercompanion-714c4.firebaseio.com"
#define FIREBASE_AUTH "dYvCq162RPegfqSf3For3GfgSz6SJX134lFaxQWQ"

//#define FIREBASE_HOST "smartdisaster-a180c.firebaseio.com"
//#define FIREBASE_AUTH "lsajM4OtCdSmMwRKe30mmArzu2YmhsDBQ5EwPuiI"


//#define WIFI_SSID "SDC-Hotspot" // Change the name of your WIFI
//#define WIFI_PASSWORD "poiuytrewq" // Change the password of your WIFI
//#define WIFI_SSID "Haqi" // Change the name of your WIFI
//#define WIFI_PASSWORD "muhabdulhaq" // Change the password of your WIFI
//#define WIFI_SSID "nodemcu" // Change the name of your WIFI
//#define WIFI_PASSWORD "passwordnodemcu" // Change the password of your WIFI
#define WIFI_SSID "SW2D" // Change the name of your WIFI
#define WIFI_PASSWORD "12345678" // Change the password of your WIFI



float latitude = 28.5458,longitude =77.1703;int fireState=0;

char last;
char indeks1[BUFFER];
char indeks2[BUFFER];
char indeks3[BUFFER];

char j;

char buff[BUFFER];

char variable;
//



void setup() {
   // put your setup code here, to run once:
  Serial.begin(115200);

  // connect to wifi.
  WiFi.begin(WIFI_SSID, WIFI_PASSWORD);
  Serial.print("connecting");
  while (WiFi.status() != WL_CONNECTED) {
    Serial.print(".");
    delay(500);
  }
  Serial.println();
  Serial.print("connected: ");
  Serial.println(WiFi.localIP());
  
  Firebase.begin(FIREBASE_HOST, FIREBASE_AUTH);
  delay(2000);

for(char i=0;i<10;i++){
   // get value 
  
  Serial.print("ConnectFlag: ");
  float data;

  data = Firebase.getFloat("connectFlag");
  Serial.println(data);
  //if(data!=1){ Firebase.begin(FIREBASE_HOST, FIREBASE_AUTH);}
  delay(500);
  

}
  pinMode(LEDBUILTIN,OUTPUT);
  
  digitalWrite(LEDBUILTIN,LOW);
  delay(10);
  digitalWrite(LEDBUILTIN,HIGH);
  delay(10);
  digitalWrite(LEDBUILTIN,LOW);
  delay(10);
  digitalWrite(LEDBUILTIN,HIGH);
  
  
   //Interrupt handler 1ms
   interrupt.attach_ms(1, interruptHandler); 
  
 
}


int intervalTime=100;
void loop() {
 static int nowTime,prevTime;
  

  nowTime = millis();
  // put your main code here, to run repeatedly:
if(nowTime-prevTime>intervalTime){

  //if(Firebase.getFloat("connectFlag")){
  Firebase.getFloat("connectFlag");
  
  Firebase.setFloat ("users/-LVYjfOXuFxSGghwi3bl/dtLat",latitude);
  if(Firebase.failed()){//Serial.println("Lat Error = " + Firebase.error());
}
  Firebase.setFloat ("users/-LVYjfOXuFxSGghwi3bl/dtLon",longitude);
  if(Firebase.failed()){//Serial.println("Long Error = " + Firebase.error());     
}
  Firebase.setInt ("users/-LVYjfOXuFxSGghwi3bl/dtApi",fireState);
  if(Firebase.failed()){//Serial.println("api =  " + Firebase.error());
}

  //}

  digitalWrite(LEDBUILTIN, !(digitalRead(LEDBUILTIN)));  //Invert Current State of LED 
prevTime = nowTime;
}
}




void interruptHandler()
{static char flag1,flag2,flag3;
  static int countSerial ,flagSerial;
   if(Serial.available()>0){
   
     byte incomingByte = Serial.read();
      
    if(incomingByte=='#'){
      countSerial=0;flagSerial=1;last=1;}
    else {
      countSerial++;
      if(countSerial<BUFFER){
           buff[countSerial] = incomingByte;
          }
      }
   
    //Parsing serial
      if(incomingByte=='!' && flagSerial == 1){ flagSerial = 0;

        for (int i=1; i<=3; i++) //jumlah data
        {   
          for (j=0; j<11; j++) //panjang data
         {
                    if (buff[j+last]==',' || buff[j+last]=='!'||buff[j+last]=='\0') {
                      last = last + j + 1;
                      break;
                      }
                    
                    switch (i) {
                      case 1: indeks1[j] = buff[j+last]; 
                      case 2: indeks2[j] = buff[j+last];
                      case 3: indeks3[j] = buff[j+last];
                    }
          }
          
         
              switch (i) {
                case 1: indeks1[j] = '\0';
                case 2: indeks2[j] = '\0';
                case 3: indeks3[j] = '\0';
      
              }
                 
     }
         
      latitude         =atof(indeks1);
      longitude        =atof(indeks2);
      fireState        =atoi(indeks3);  

          

//  Serial.print("Latitude = ");
//  Serial.print(latitude);
//  
//  Serial.print(" || Longitude = ");
//  Serial.print(longitude);
//
//  Serial.print(" || fireState = ");
//  Serial.println(fireState);

      
      }

  }
//
//
wdt_reset();

}

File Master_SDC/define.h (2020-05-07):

#ifndef _DEFINE_H
#define _DEFINE_H

#include <SoftwareSerial.h> 
#include <TinyGPS++.h> 
#include <Wire.h>
#include <LiquidCrystal.h>
#include "pitches.h"
TinyGPSPlus gps; // create gps object 



const int rs = 2, en = 3, d4 = 4, d5 = 5, d6 = 6, d7 = 7;
LiquidCrystal lcd(rs, en, d4, d5, d6, d7);

SoftwareSerial gpsSerial(10,11);//rx,tx 

#define fireSensor2   0x25
#define fireSensor1   0x31
#define BUZZER_PIN 12
#define LEDBUILTIN 13

#define BUTTON4   A0
#define BUTTON3   A1
#define BUTTON2   A2
#define BUTTON1   A3




extern void GetGPS();
extern double latitude,longitude;
extern void Buzzer();
#endif

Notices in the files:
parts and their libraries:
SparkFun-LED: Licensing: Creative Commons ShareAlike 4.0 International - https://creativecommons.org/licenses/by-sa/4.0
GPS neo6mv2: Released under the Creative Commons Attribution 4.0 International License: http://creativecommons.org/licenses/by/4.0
